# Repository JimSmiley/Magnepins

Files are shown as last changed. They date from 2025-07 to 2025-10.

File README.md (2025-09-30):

This is a repository for the open source, low cost refreshable braille and tactile display "Magnepins", [https://dl.acm.org/doi/10.1145/3746059.3747692](url) presented at UIST2025. 
Many updated iterations since the paper, and this repo is a work in progress.  Please feel free to get in touch if you are interested in building a device.

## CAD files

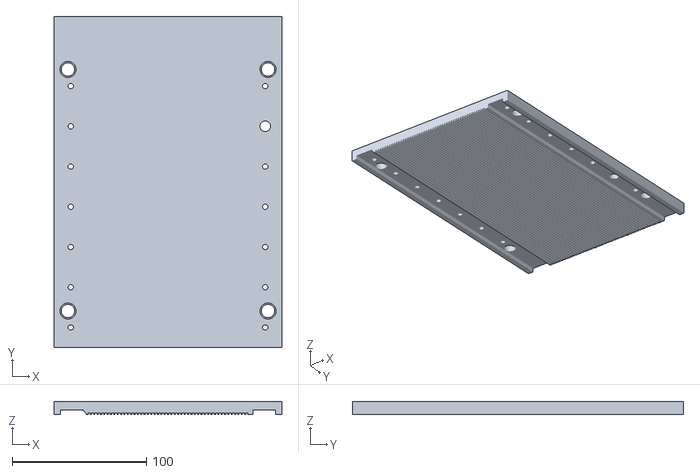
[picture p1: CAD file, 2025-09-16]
48RowLockingChannel.stl
170.0 x 247.0 x 9.70

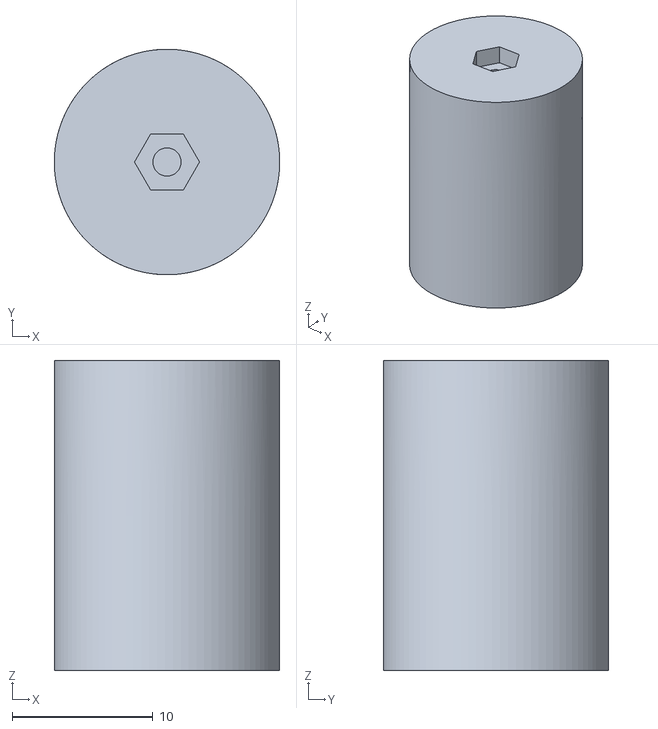
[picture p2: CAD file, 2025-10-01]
STL files/WinderThreadMount.stl
16.0 x 16.0 x 22.0

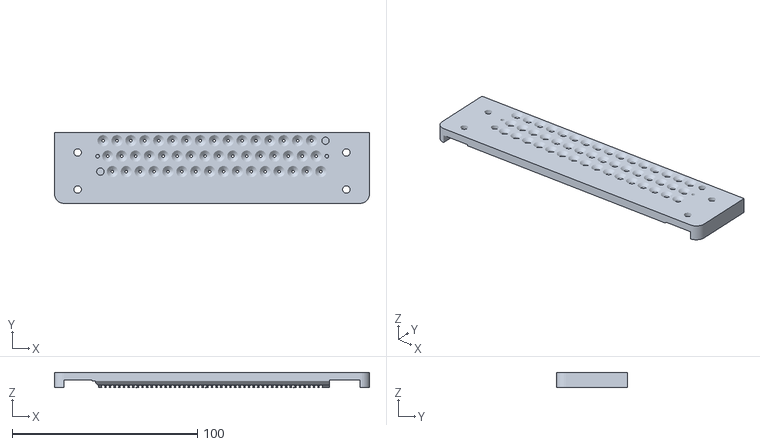
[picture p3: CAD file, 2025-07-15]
STL files/48ROW.stl
170.0 x 38.2 x 8.20

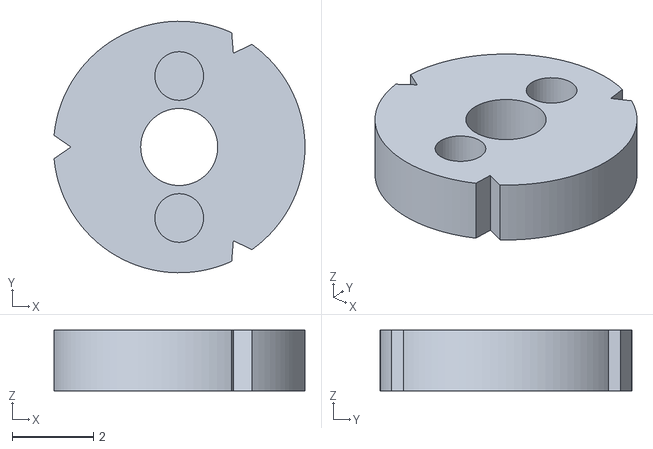
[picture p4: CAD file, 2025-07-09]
STL files/ElectromagnetEnds.stl
6.19 x 6.20 x 1.50

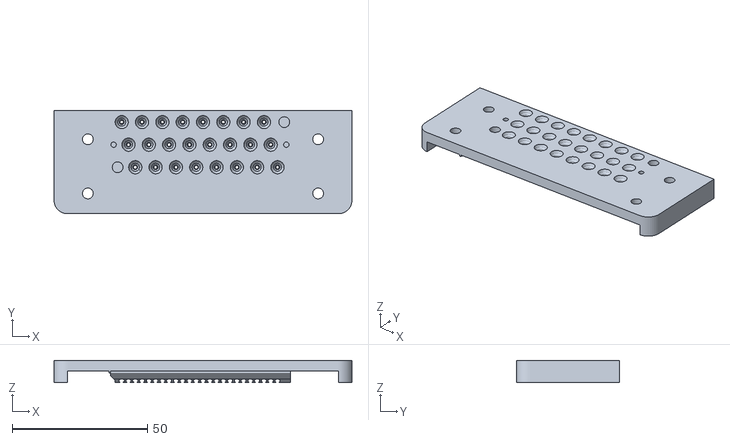
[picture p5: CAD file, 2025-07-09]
STL files/ActuatorPlate1point2.stl
110.0 x 38.2 x 8.20

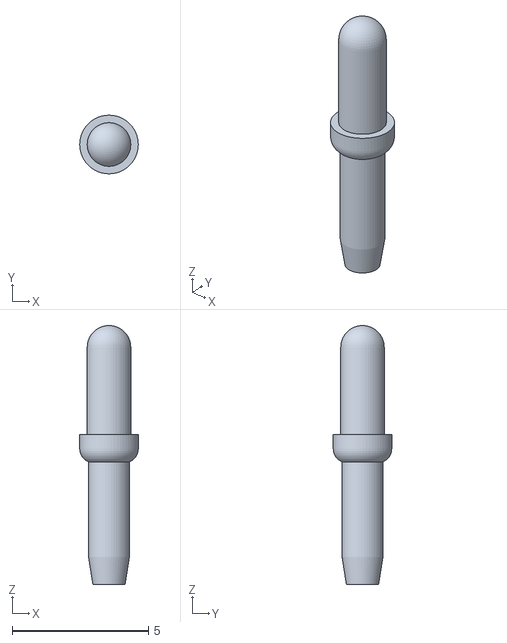
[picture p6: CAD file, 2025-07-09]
STL files/singlePin.stl
2.15 x 2.15 x 9.50

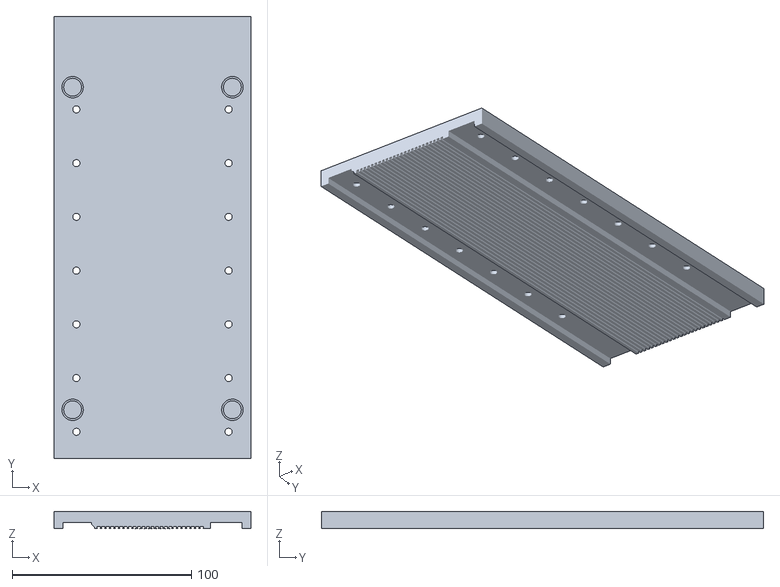
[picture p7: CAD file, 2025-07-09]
STL files/locking.stl
110.0 x 247.0 x 9.70

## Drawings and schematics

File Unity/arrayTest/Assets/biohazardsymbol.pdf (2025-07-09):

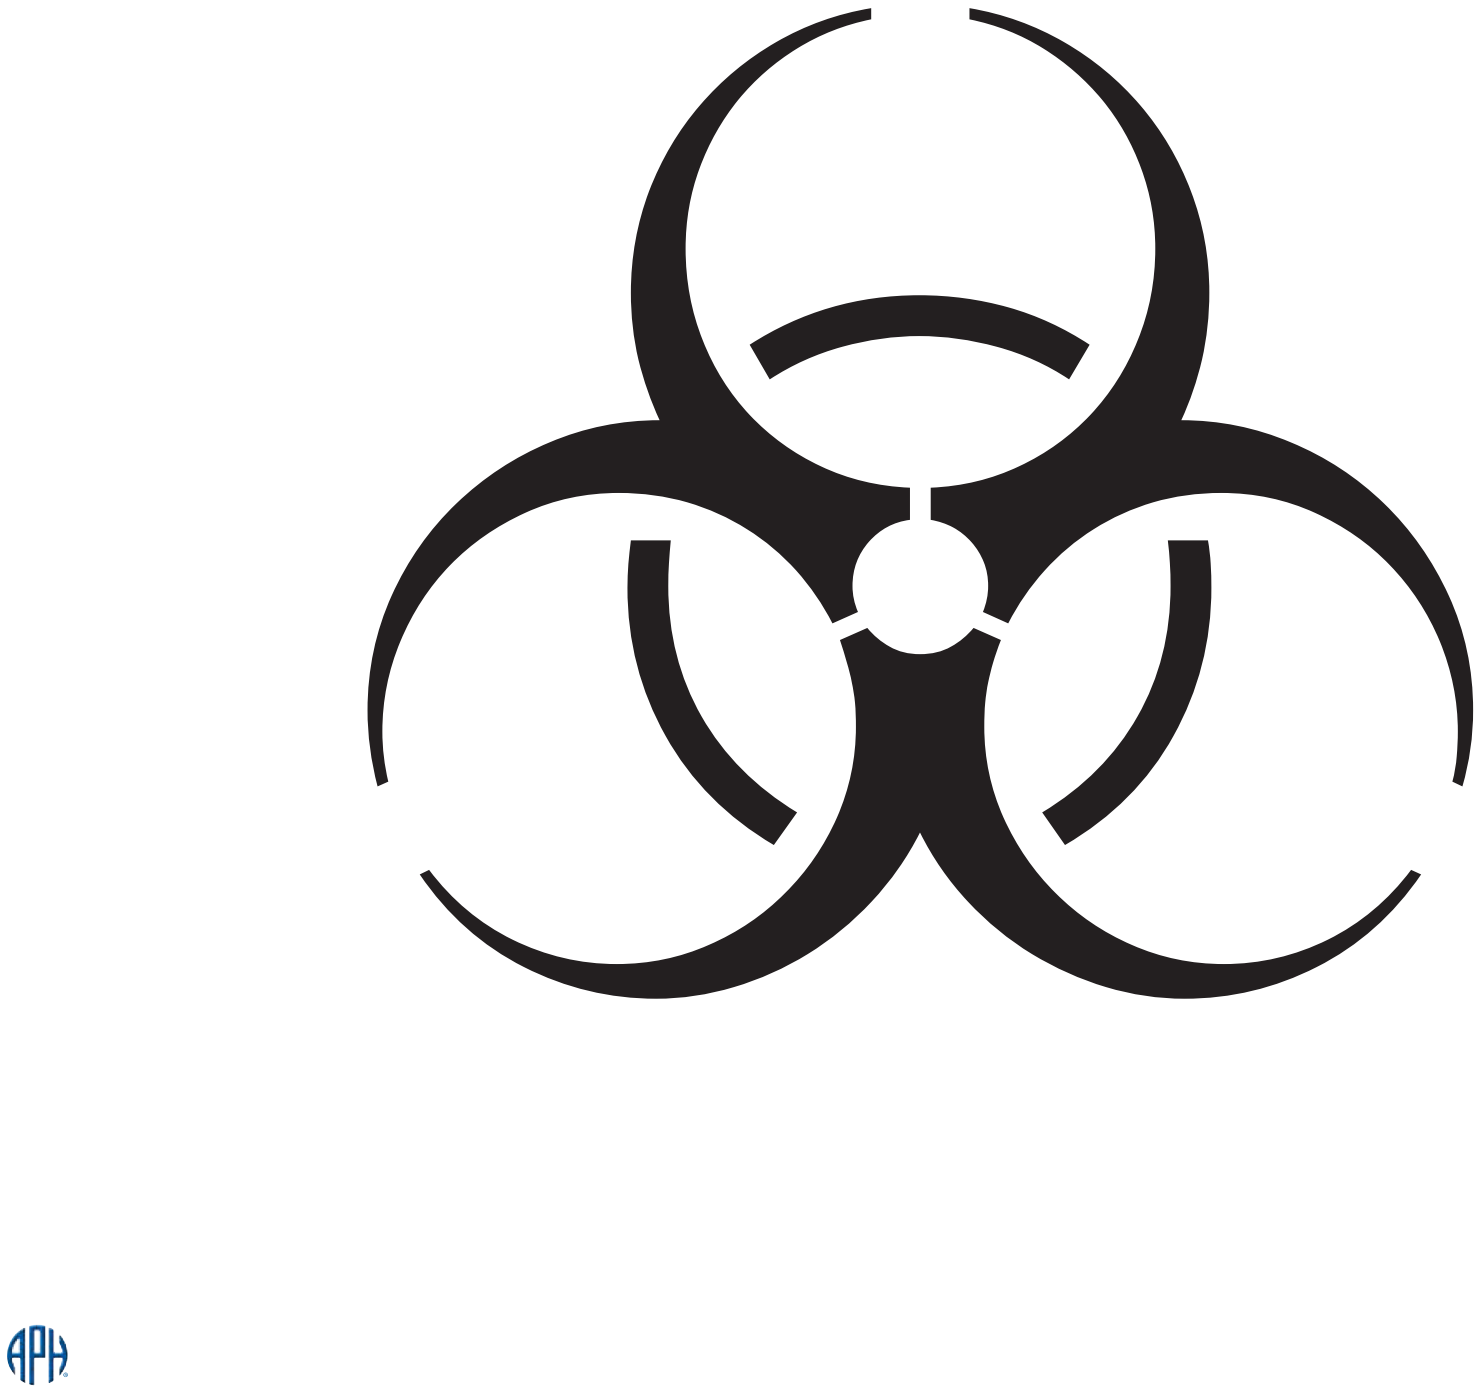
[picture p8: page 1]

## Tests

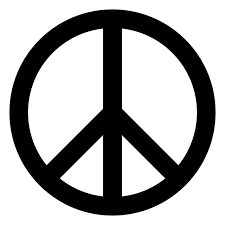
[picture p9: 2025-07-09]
Unity/arrayTest/Assets/download.png

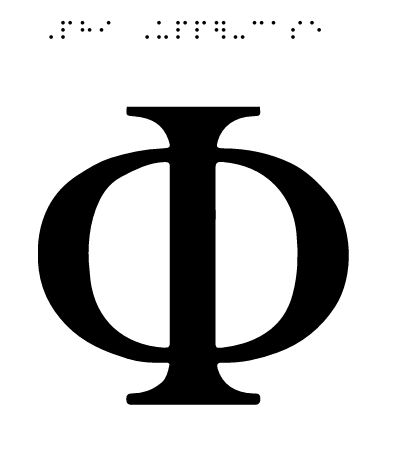
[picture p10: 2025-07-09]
Unity/arrayTest/Assets/PHI.PNG

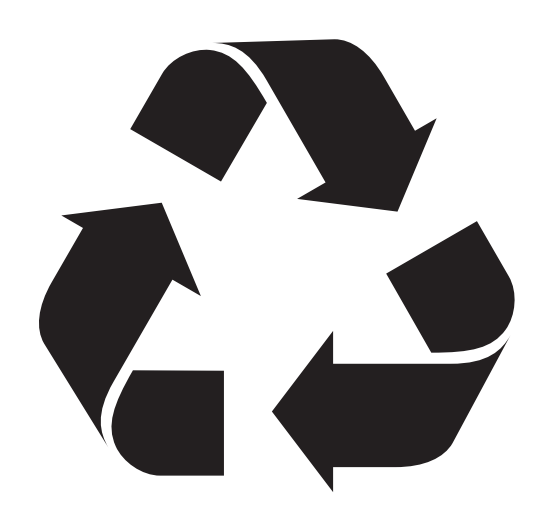
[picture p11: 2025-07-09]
Unity/arrayTest/Assets/recycling.PNG

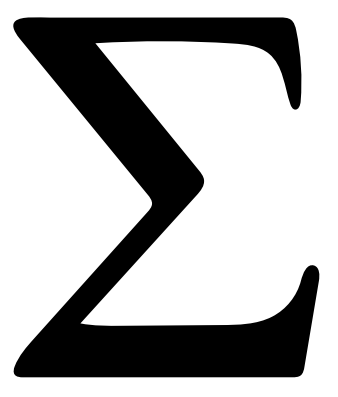
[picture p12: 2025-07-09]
Unity/arrayTest/Assets/sigma.PNG

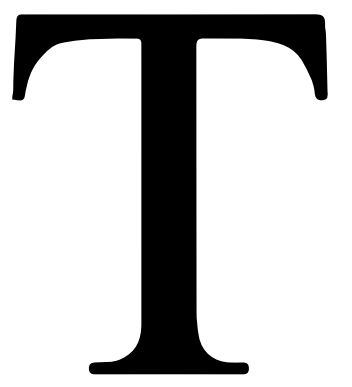
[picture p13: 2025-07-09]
Unity/arrayTest/Assets/tau.PNG

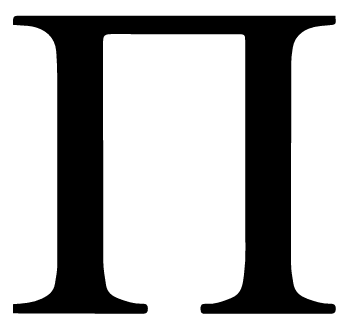
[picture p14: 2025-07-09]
Unity/arrayTest/Assets/pi.PNG

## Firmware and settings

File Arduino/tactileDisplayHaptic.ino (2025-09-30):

   
long startMicros;
long endMicros;
long pulsePeriod;

long startMillisArray[3];

long startHaptics;

long endMillis;
///////////// use these for troubleshooting refresh rate
long countTime;
long oldCountTime;
long fastestTime=1000;
long slowestTime =10;
/////////////////////////////////////

bool isBrailleSpacing= false;
int count;
int oldCount;
int trigCount;
int timeoutCount = 4;


bool holdArray[3];

bool motorHold;
long motorStart;

int offsets[3]={-6,2,10}; //  group spacings are 8.33 mmm apart - offsets are 0.1mm.



// const byte encoderA = 4;
const byte encoderB = 4;
const int enablePin = 6;
const int vibMot1 = 8;
const int vibMot2 = 10;


int outs[3][8] = { {23, 27,  29, 33,43,47,49,53}, {24,25, 34,31,40,45,50, 51},{22,26, 30,36,38,44,46, 52}}; 



int arraySizes[3];

bool firstRead;
bool secondRead;

bool up;
bool pass;
int currentVal;
int currentVal2;
int passCount;


bool startingPoint[3];


bool hapticsRunning;
bool evenPass;
bool hitUpper;
bool hitLower;
int modulo3 = 25;
int speedOffset;
float speedOffsetScale;
int alternateOffset =0;


int spacingOffsets[3];


char theArray[96][24]; //Width x height Beware when sending writing driver software for serial strings! 96 is additional headroom, the display is 89 pins currently

char pinVals[3][8][100];


char charOne = '1';
int rows = 24;
int columns =96; // extra headroom once again. 


int columnArray[3];



bool serialRead;
bool newLineRecieved;
int lineCountSerial;
bool rowSet;
bool writeHighOnSetup;

int actuateCount[3];

bool tooFast;

int distanceCutoff = 25;

void setup() {
  Serial.begin(115200);
  //delay (3000);
  Serial.println("running");
  arraySizes[0] = sizeof outs[0]/sizeof outs[0][0];
  arraySizes[1] = sizeof outs[1]/sizeof outs[1][0];
  arraySizes[2] = sizeof outs[2]/sizeof outs[2][0];

  pinMode(2, INPUT); // digital 2
  pinMode (vibMot1, OUTPUT);
  pinMode (vibMot2, OUTPUT);

  pinMode(encoderB, INPUT); // digital 3
  for (int i = 0; i< arraySizes[0]; i++)
  {
  pinMode(outs[0][i], OUTPUT);

  }
  for (int i = 0; i<arraySizes[1]; i++)
  {
  pinMode(outs[1][i], OUTPUT);

  }
  for (int i = 0; i<arraySizes[2]; i++)
  {
  pinMode(outs[2][i], OUTPUT);

  }
  //pinMode(enablePin, OUTPUT);

  attachInterrupt(digitalPinToInterrupt(2), Interrupt, CHANGE );
  digitalWrite(vibMot1, HIGH);
  digitalWrite(vibMot2, HIGH);
  delay (1000);
  digitalWrite(vibMot1, LOW);
  digitalWrite(vibMot2, LOW);
}

void loop() {

if (hapticsRunning)
{
  long currentTime  =millis();
  if (currentTime - startHaptics > 100) // haptic pulse duration. Todo make variable
  {
  digitalWrite(vibMot1, LOW);
  digitalWrite(vibMot2, LOW);
  hapticsRunning = false;
  }
}
  // ReadLines();
  FillArray();

  if (oldCount != count)
  {
    long currentTime = micros();
    countTime = currentTime - oldCountTime;
    oldCountTime =currentTime;

    if (countTime < 1800 && count >oldCount) //Disable pin actuation if carriage moves faster than threshold
    {
      tooFast = true;
      
    }
    else if (countTime >=1800)
    {
      tooFast = false;
    }
  
    
  
    CheckStartingPoint();


    oldCount = count;
    
    columnArray[0] = ((count -offsets[0] - spacingOffsets[0] - startingPoint[0]) /25) - 3;
    columnArray[1] = ((count -offsets[1] - spacingOffsets[1] - startingPoint[1]) /25) - 6;
    columnArray[2] = ((count - offsets[2] - spacingOffsets[2] - startingPoint[2]) /25) - 9;

    if (isBrailleSpacing) // Recommend deprecating braille spacing. Makes things too complicated having reduced spacing between cells, but will depend on whether users identify it as a priority
    {
      spacingOffsets[0] = ((columnArray[0])/3) *-5; // 
      spacingOffsets[1] = ((columnArray[1])/3) *-5;
      spacingOffsets[2] = ((columnArray[2])/3) *-5;
    }


    for (int i = 0; i < 3; i++){
      if ((count - offsets[i] - spacingOffsets[i] ) %25 ==0   && startingPoint[i] && !holdArray[i]) //  && startOffset1 //spacingOffsets[0]
      {
        if (up)
        {  
          startMillisArray[i] = millis();
          actuateCount[i] = count; 
           if (!tooFast)
            {
             
          Actuate(i);       
            }  
            else
            {
              HapticPulse(); 
            }
        }
      }
    }
  }

  for (int i = 0; i < 3; i++){
    if (holdArray[i])
    {
      if (millis() - startMillisArray[i]> 15) // This is the electromagnet pulse duration, 15ms seems best, however improved magnetics and coil design may change this. TODO change to variable. 
      {
      
        for (int j = 0;  j < arraySizes[i]; j++)
        {
          digitalWrite(outs[i][j], LOW);
        }
      
        holdArray[i] = false;
      }
    }
  }
}
void CheckStartingPoint() // These points depend on the positioning of the timing strip in relation to the display module
{
   if (count >85 )
    {
       startingPoint[0] = true;
    }
    else
    {
      startingPoint[0] = false;
      columnArray[0] = 0;
      spacingOffsets[0] = 0;
    }

    if (count >145 ) //145
    {
       startingPoint[1] = true;
    }
    else
    {
      startingPoint[1] = false;
      columnArray[1] = 0;
      spacingOffsets[1] = 0;
    }
     if (count >195) //206ish
    {
       startingPoint[2] = true;
    }
    else
    {
      startingPoint[2] = false;
      columnArray[2] = 0;
      spacingOffsets[2] = 0;
    }
}

void HapticPulse()
{
  startHaptics = millis();
  digitalWrite(vibMot1, HIGH);
  digitalWrite(vibMot2, HIGH);
 hapticsRunning = true;
}


void Actuate (int pinGroup) 


{   
  
  for (int i = 0; i< arraySizes[pinGroup]; i++)
  {     
    
    if (pinVals[pinGroup][i][columnArray[pinGroup]] == '0'|| !writeHighOnSetup)
    {  
      digitalWrite (outs[pinGroup][i], HIGH);
      holdArray[pinGroup] = true;
    }      

  }        
}

void FillArray()
{
  char endMarker = '\n';
  char rc;
  int row;
  int column;
  int pinGroupIndex;

    while (Serial.available() > 0 && !serialRead) {
       writeHighOnSetup = true;
          rc = Serial.read();
          if (rc == 'b')
          {
            isBrailleSpacing = true;      
            
            Serial.println("braille");
          }
        else if (rc == 't')
          {
            isBrailleSpacing = false;     
              Serial.println("tactile"); 
          
          }
        
      else{
          if (rc != endMarker) { 
            if (!rowSet)
            {
              //count =0;  // this stops drift, but requires fully  set back.
              row = 3; 
              column = 0; 
              pinGroupIndex = 0;
              rowSet = true;
            
            }
            
            if (row ==3)
            {
              pinVals[2][pinGroupIndex][column] = rc;
            

              
            }
              else if (row ==2)
              {
                  pinVals[1][pinGroupIndex][column] = rc;
                
              
              }
              else if (row ==1)
              {
                  pinVals[0][pinGroupIndex][column] = rc;
              
              }
        
              if (column < columns-1)
              {
              column++;
              }
              else
              {
                column = 0;
                if (row >1)
                {
                row --;
                }
                else
                {
                  row =3;
                  pinGroupIndex ++;
              
                }
                
              }
        
          }

          else
          {
            //Serial.println("end");
            row = 3;
            column = 0;
            pinGroupIndex = 0;
            rowSet= false;
            //count = 0;
            fastestTime=1000;
            slowestTime = 10;
          }
          
  }
  }

}
void Interrupt()
{
 
  if (bitRead(PINE, 4))// reading itself to determine rising or falling. This is rising edge
  {
    firstRead = bitRead(PING, 5); // read other encoder o
  }
  else // read again on falling edge. This filters out erroneous triggers if encoder is twitched back and forth while right on the edge of a trigger.
  {
    
    secondRead = bitRead(PING, 5);
    if (firstRead && !secondRead)
    {
     
      count--;
      up = false;
      if (count <0)
      {
        count = 0;
      }
     
    }
    else if (!firstRead && secondRead)
    {
     startMicros = micros();
     
     pulsePeriod= startMicros - endMicros;
    
     endMicros = micros();
      count ++;
     up =true;
    }
  }  
}

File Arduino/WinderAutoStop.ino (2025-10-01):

#include <AccelStepper.h>
int  count;
int oldCount;
int revolution;
int revsPerWind = 635;
bool dir;
const int dirPin = 13;
const int stepPin = 12;
//const int enablePin = 0;
bool atEnd;
int motorSpeed;
int passes;
int slowDownCount = 8000;
bool finishOverride = false; // 
// Define motor interface type
#define motorInterfaceType 1

// Creates an instance
AccelStepper myStepper(motorInterfaceType, stepPin, dirPin);

void setup() {
  
  
  Serial.begin(115200);
 //pinMode(enablePin, OUTPUT);
 pinMode(11, OUTPUT);
 pinMode(10, INPUT); // set to INPUT for HIGH impedence on L1 and L2 = 0.5a current limit. change to output and 
 pinMode(9, INPUT);
  pinMode(8, OUTPUT);
 pinMode(7, INPUT);
 pinMode(6, INPUT);
   pinMode(5, OUTPUT);
  pinMode(3, OUTPUT);
 pinMode(4, OUTPUT);
 pinMode (2, OUTPUT);

 digitalWrite(11, HIGH); // slp
digitalWrite(4, HIGH);
digitalWrite(3, LOW);
//digitalWrite (5, HIGH);
digitalWrite(8, HIGH); // QUARTER STEP. Low for full step
 

  myStepper.setMaxSpeed(10000);
  myStepper.setAcceleration(10000);
  myStepper.setSpeed(10000);
//  digitalWrite(enablePin, LOW);
 attachInterrupt(digitalPinToInterrupt(7), Interrupt, RISING);
}
//One step = 0.125mm so 50 steps for .625mm. 200 for 2.5

void loop() {


motorSpeed = analogRead(A4);
if (analogRead(A5) > 800 && motorSpeed < 10) // flip a switch with speed dial down and can keep winding after finish. 
{
  finishOverride = true;
  atEnd = false;
  
}
int scaleVal = map(motorSpeed, 0, 1023, 0, 255);
if (!atEnd)
{
analogWrite(5, scaleVal);
}
else
{
  int slowVal = map(slowDownCount, 0, 8000, 0, 255);
  analogWrite(5, slowVal);
  if (slowDownCount > 0)
  {
  slowDownCount --;
  }
  
}
  if (count != oldCount)
  {
   // Serial.println(count);
    oldCount = count;
    if (count >=22)
    {
      count = 0;
      
      
      if (revolution > revsPerWind)
      {
        passes ++;
        revolution = 0;
        dir = !dir;
        Serial.println (passes);
      }
      moveStepper(dir);
      revolution ++;
    }
  }
  if (!atEnd && passes ==14 && !finishOverride)
  {
    digitalWrite (2, HIGH);
    atEnd  = true;
  }
  
myStepper.run();

   
   }
void moveStepper(bool up)
{
  if (up)
  {
  myStepper.moveTo(myStepper.currentPosition()+1);
  }
  else
  {
    myStepper.moveTo(myStepper.currentPosition()-1);
  }
  
}
   void Interrupt()
{
 if (digitalRead(6) ==HIGH)
 {
  count --;
 }

 else
 {
  count++;
 }
}
 

  
 

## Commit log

2025-07-09 Added Unity project and stl files. Dxfs and tutorials to follow
    [ActuatorPlate1point2.stl, ElectromagnetEnds.stl, locking.stl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]
2025-07-15 Add files via upload
    for 48Row unit. Holes should be 1.2mm but have been enlarged to compensate for shrinkage. Use a 1.2mm bit to clean them up.
    [48ROW.stl]
2025-07-25 Add files via upload
    Arduino code for electromagnet winding machine.
2025-09-16 added 48Rowlockingchannel stl
    [48RowLockingChannel.stl]
2025-09-30 Adds vibration motors on pins 8 and 10 for haptic feedback.
    Monitors carriage speed and refuses to actuate if moving too fast to avoid pin jams. Gives haptic feedback via vibration motors on handle instead
    [tactileDisplayHaptic.ino]
2025-10-01 Arduino code for custom electromagnet winding machine
    Custom winder code. This machine uses a https://www.pololu.com/product/4757 motor, and stepper motor to automatically wind electromagnets. More details to come.
2025-10-01 adapter to mount electromagnet blank to winding machine.
    needs an M2 nut inserted. Or modify to use a m2 thread insert
    [WinderThreadMount.stl]
